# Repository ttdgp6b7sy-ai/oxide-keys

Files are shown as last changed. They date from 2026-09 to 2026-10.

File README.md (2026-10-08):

# Oxide Keys

A mini game console with 8 keys and a display, which has the ability to play very simple games to kill time and also a fun way to integrate Rust (the language I am learning).

The hardware is mainly composed of an 8-key mini game player with rotary encoder, LCD display that folds on a hinge, and RGB underglow on the Raspberry Pi Pico W, where I aim to include as much Rust as I can in this project.

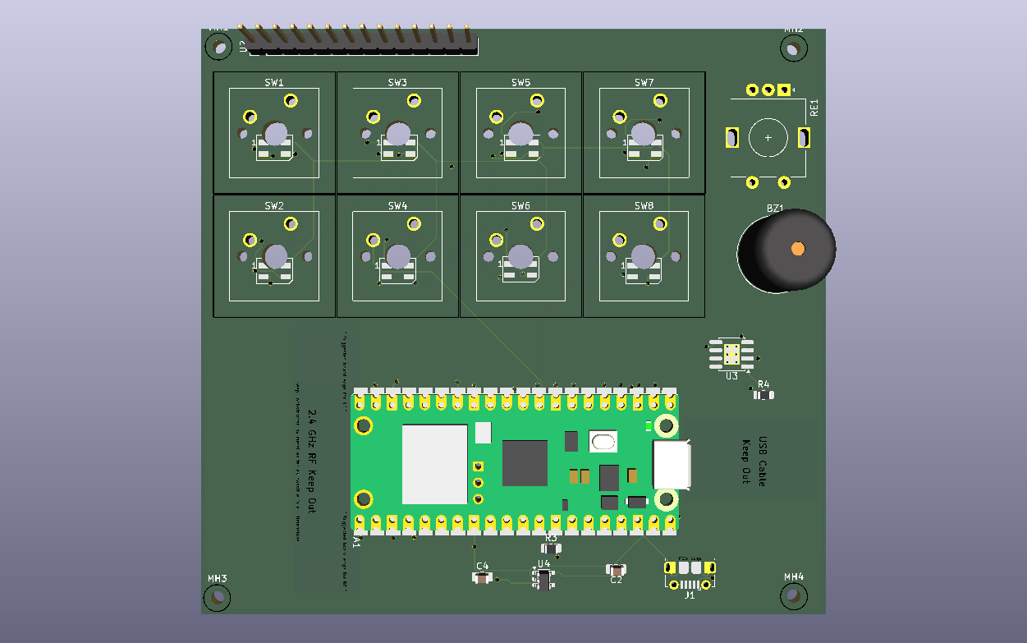
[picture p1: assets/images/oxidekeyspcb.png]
Oxide Keys Pcb Board





## CAD views
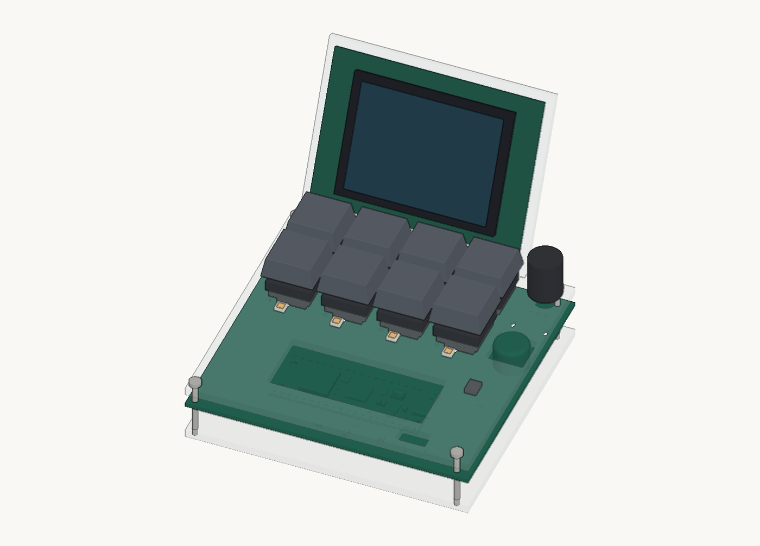
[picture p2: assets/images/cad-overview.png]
Oxide Keys with the parts in place

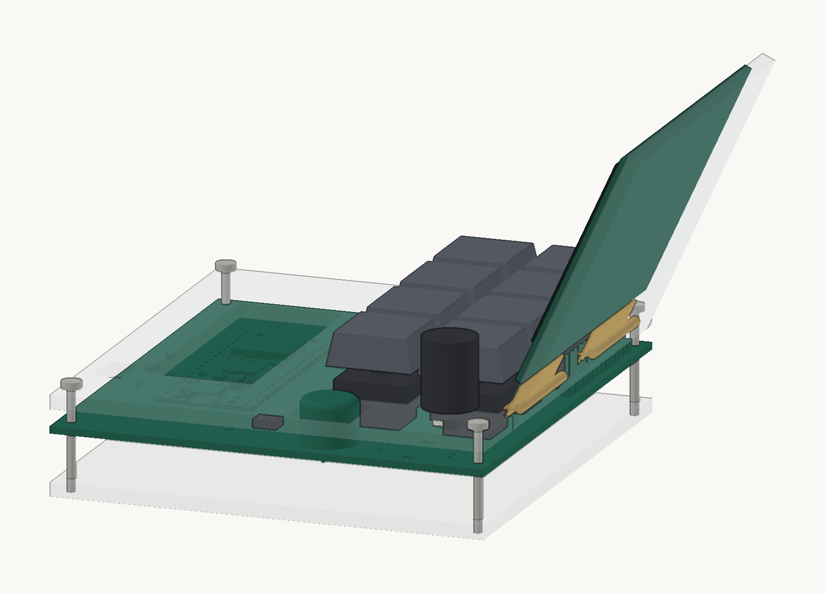
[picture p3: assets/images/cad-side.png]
Oxide Keys CAD from the side

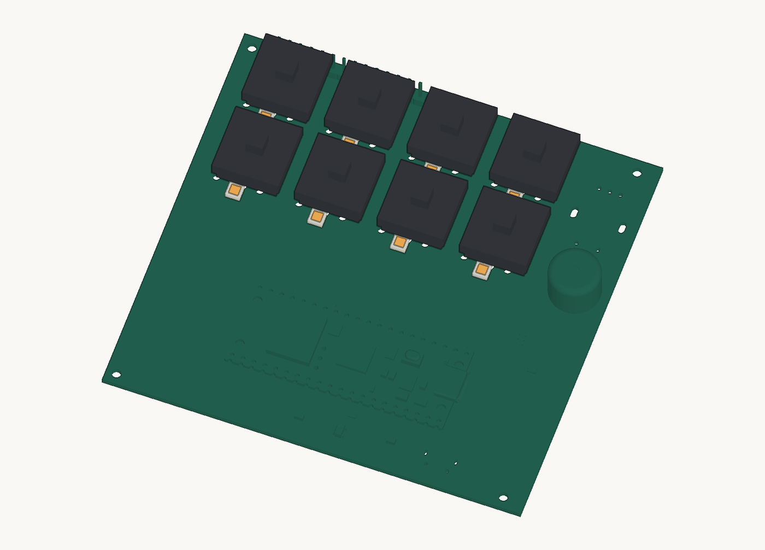
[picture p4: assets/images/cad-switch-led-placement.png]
Switches and LEDs on the PCB

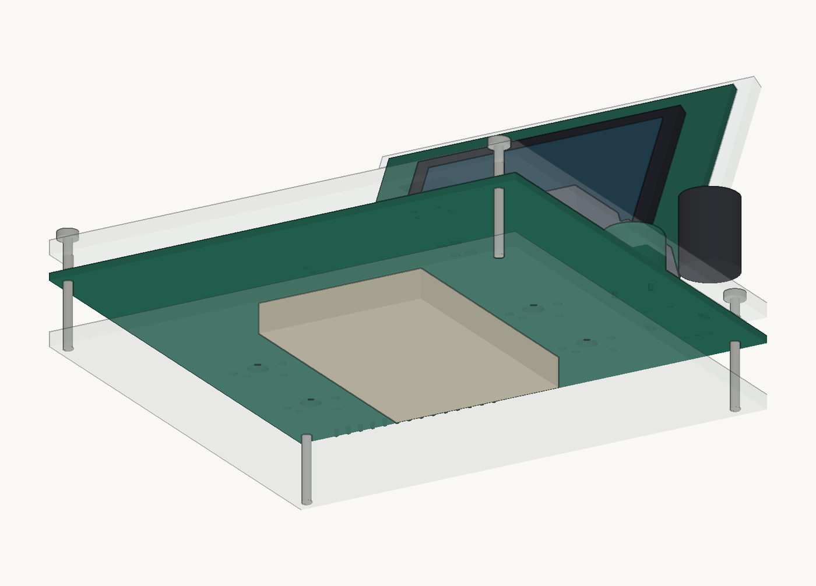
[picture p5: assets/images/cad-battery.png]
Battery below the PCB


[Assembly STEP](cad/OxideKeys-review-assembly-detailed.step) · [Enclosure SVG](cad/Oxidekeysenclosure.svg)

## Demo
No physical build yet but the image above shows the PCB board to be made.

## Location of stuff
- `firmware/` Rust code for the Pico W
- `pcb/` KiCad project and gerbers
- `cad/` 3D model and layout for enclosure
- `BOM.csv` parts list

## Quickstart

**Get the files**
Clone the repo or download extract zip from github repo.
`git clone https://github.com/ttdgp6b7sy-ai/oxide-keys.git`
`cd oxide-keys`

**Flash the firmware**
1. Hold the bootsel button on the pico W while plugging it into USB, it will appear as a drive.
2. Drag `firmware/oxide-keys.uf2` onto that drive and then it reboots on its own.

**Build the firmware yourself**
1. install rust from https://rustup.rs if you haven't already
2. `rustup target add thumbv6m-none-eabi`
3. `cargo install flip-link elf2uf2-rs --locked`
4. `cd firmware`, then `cargo build --release`
5.  convert to UF2: `elf2uf2-rs target/thumbv6m-none-eabi/release/oxide-keys oxide-keys.uf2`, then drag it onto the pico as above

**3d model**
The full assembly is `cad/OxideKeys-review-assembly-detailed.step`

## Features that I will implement
- The switches are designed so that each key is important in navigating the screen where I want to create a launcher which you can scroll through a section of simple games similar to pong and space invader that I create. These keys will be assigned certain roles in the future such as selecting, navigation (mimicking the hjkl keys etc), and the amount of keys allows a wide use-case in games that I will develop specifically for this device.
- The lights underneath the keys will be an amber glow until pressed in which they will react in a white colour once pressed.
- Want the encoder knob to be used to scroll on the idle screen/Launcher.

## Design
- Uses a pico W as the controller.
- firmware stack includes embedded hal, probers and rp2040 hal. It lives in firmware/ and builds with cargo build
- display sits on a hinge now
- fullparts list is in [BOM.csv](BOM.csv).
- the cad enclosure that I am incorporating uses a 2d laser cut acrylic with mounted standoffs in between. Meaning that I can still incorporate cool aesthetics with the layer being transparent on purpose.

## Todo
The potential of the encoder knob in some games is something I want to explore.

## Credits
credits to stardance for inspo + help.

## Bill of materials

The source BOM with supplier links is in [BOM.csv](BOM.csv).

| Part | Quantity | Price AUD | Supplier | Link |
| --- | ---: | ---: | --- | --- |
| Raspberry Pi Pico W | 1 | 9.90 | Core Electronics | [link](https://core-electronics.com.au/raspberry-pi-pico-w-wireless-wifi.html) |
| Piezo Buzzer | 1 | 0.34 | Core Electronics | [link](https://core-electronics.com.au/piezo-buzzer.html) |
| LiPo Battery 3.7V 1100mAh | 1 | 10.15 | Tempero Systems | [link](https://temperosystems.com.au/products/603450-lithium-ion-polymer-battery-lipo-3-7v-1100mah/) |
| Core Electronics Shipping | 1 | 7.00 | Core Electronics | [link](https://core-electronics.com.au/policies-faq) |
| Cherry MX2A Orange Switch pack (10x) | 1 | 6.50 | Mechstock | [link](https://www.mechstock.com.au/products/cherry-mx2a-orange) |
| Mechstock Shipping | 1 | 7.50 | Mechstock | [link](https://www.mechstock.com.au/pages/shipping-policy-2025) |
| Rotary Encoder Switch (SR1230) | 1 | 10.25 | Jaycar | [link](https://www.jaycar.com.au/rotary-encoder-switch-with-pushbutton/p/SR1230) |
| Silicone Wire 2m (28AWG Red + Black) | 1 | 4.95 | Amazon AU | [link](https://www.amazon.com.au/Ozchillon-28AWG-Flexible-Silicone-Black/dp/B0FTVY5H6M) |
| Pin Header Strip 40-way (M+F) | 1 | 2.95 | Jaycar | [link](https://www.jaycar.com.au/pcb-pins-and-headers/c/1HJ) |
| 1N4148 Diode Pack (5x) | 1 | 0.95 | Jaycar | [link](https://www.jaycar.com.au/1n4148-1n914-signal-diode-pack-of-5/p/ZR1100) |
| 2.4" TFT LCD Touch Display (ILI9341) | 1 | 10.00 | Createunsw | [link](https://store.createunsw.com.au/2-4-arduino-touchscreen-module) |
| M2 Nylon Standoff Kit (180pc) | 1 | 15.00 | Amazon AU | [link](https://www.amazon.com.au/Aolidsive-Standoff-Assortment-Motherboard-Projects/dp/B0GYBV21GF) |
| Clear Acrylic Sheet A5 3mm | 2 | 8.96 | Amazon AU | [link](https://www.amazon.com.au/Clear-Acrylic-Sheet-3mm-Thickness/dp/B0F4PN42ZM) |
| Knurled Encoder Knob (2pc) | 1 | 7.34 | Core-electronics | [link](https://core-electronics.com.au/slim-rubber-rotary-encoder-knob-11-5mm-x-14-5mm-d-shaft.html) |
| N3UD PBT Blank Keycaps 1U XDA Profile (20pc) | 1 | 7.00 | AliExpress | [link](https://www.aliexpress.com/w/wholesale-n3ud-20pcs-pbt-blank-keycap-xda.html) |
| Amazon AU Shipping (order remaining Amazon items together) | 1 | 0.00 | Amazon AU | [link](https://www.amazon.com.au/) |
| SK6812MINI RGB LED pack (x20) | 2 | 3.00 | KEEBD | [link](https://keebd.com/products/sk6812mini-rgb-led) |
| KEEBD Shipping | 1 | 9.59 | KEEBD | [link](https://keebd.com/) |
| TP4056 Li-ion Charger IC (harvest from domestic TP4056 module) | 1 | 3.99 | Tempero Systems | [link](https://temperosystems.com.au/products/tp4056-mini-usb-1a-5v-lithium-battery-charger-copy/) |
| AP2112K-3.3 LDO Regulator | 1 | 5.23 | Amazon AU | [link](https://www.amazon.com.au/) |
| 330 Ohm 0805 Resistor pack (10x) | 1 | 1.40 | Altronics | [link](https://www.altronics.com.au/electronic-components/carbon-film-resistors/?prdv=330R) |
| 1uF 0805 Capacitor pack (50x) | 1 | 13.95 | Phipps Electronics | [link](https://www.phippselectronics.com/product/16v-1uf-0805-ceramic-smd-capacitor-pack-of-50/) |
| Brass Hinges (2-pack) | 1 | 7.94 | Bunnings | [link](https://www.bunnings.com.au/prestige-15-x-25-x-0-5mm-decorative-brass-hinges_p3968293) |
| Bunnings Shipping | 1 | 0.00 | Bunnings | [link](https://www.bunnings.com.au/) |
| TOTAL (including PCB fabrication) |  | 161.79 |  |  |
| JLCPCB 4-Layer PCB Fab | 1 | 13.00 | JLCPCB | [link](https://jlcpcb.com/) |
| --- Optional, not counted above --- |  |  |  |  |
| Desertcart M2 Mounting Screw Kit (60pc) | 1 | 10.00 | Desertcart Australia | [link](https://www.desertcart.com.au/products/600128736-m2-ssd-screws-kit-pcie-nvme-m-2-ssd-mounting) |
| Soldering Iron Kit (optional) | 1 | 25.00 | Amazon AU | [link](https://www.amazon.com.au/Soldering-Iron-Kit-Rechargeable-Temperature/dp/B0DYH7QMYK) |

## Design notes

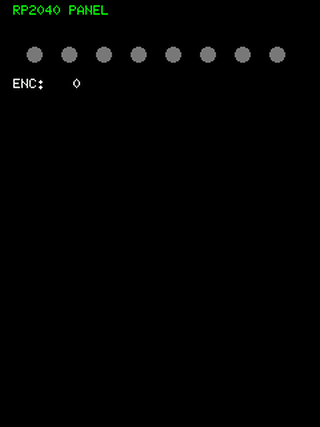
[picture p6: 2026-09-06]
firmware/wokwi-demo.gif

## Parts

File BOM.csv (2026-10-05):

Part | Quantity | Price_AUD | Price_USD | Supplier | Link | Group | Shipping
Raspberry Pi Pico W | 1 | 9.90 | 7.11 | Core Electronics | https://core-electronics.com.au/raspberry-pi-pico-w-wireless-wifi.html | Core Electronics
Piezo Buzzer | 1 | 0.34 | 0.24 | Core Electronics | https://core-electronics.com.au/piezo-buzzer.html | Core Electronics
LiPo Battery 3.7V 1100mAh | 1 | 10.15 | 7.29 | Tempero Systems | https://temperosystems.com.au/products/603450-lithium-ion-polymer-battery-lipo-3-7v-1100mah/ | Tempero Systems
Core Electronics Shipping | 1 | 7.00 | 5.03 | Core Electronics | https://core-electronics.com.au/policies-faq | Core Electronics | Standard Post
Cherry MX2A Orange Switch pack (10x) | 1 | 6.50 | 4.69 | Mechstock | https://www.mechstock.com.au/products/cherry-mx2a-orange | Mechstock
Mechstock Shipping | 1 | 7.50 | 5.39 | Mechstock | https://www.mechstock.com.au/pages/shipping-policy-2025 | Mechstock | Standard Post (est.)
Rotary Encoder Switch (SR1230) | 1 | 10.25 | 7.36 | Jaycar | https://www.jaycar.com.au/rotary-encoder-switch-with-pushbutton/p/SR1230 | Jaycar
Silicone Wire 2m (28AWG Red + Black) | 1 | 4.95 | 3.57 | Amazon AU | https://www.amazon.com.au/Ozchillon-28AWG-Flexible-Silicone-Black/dp/B0FTVY5H6M | Amazon AU
Pin Header Strip 40-way (M+F) | 1 | 2.95 | 2.12 | Jaycar | https://www.jaycar.com.au/pcb-pins-and-headers/c/1HJ | Jaycar
1N4148 Diode Pack (5x) | 1 | 0.95 | 0.68 | Jaycar | https://www.jaycar.com.au/1n4148-1n914-signal-diode-pack-of-5/p/ZR1100 | Jaycar
2.4" TFT LCD Touch Display (ILI9341) | 1 | 10.00 | 7.22 | Createunsw | https://store.createunsw.com.au/2-4-arduino-touchscreen-module | createunsw
M2 Nylon Standoff Kit (180pc) | 1 | 15.00 | 10.77 | Amazon AU | https://www.amazon.com.au/Aolidsive-Standoff-Assortment-Motherboard-Projects/dp/B0GYBV21GF | Amazon AU
Clear Acrylic Sheet A5 3mm | 2 | 8.96 | 6.43 | Amazon AU | https://www.amazon.com.au/Clear-Acrylic-Sheet-3mm-Thickness/dp/B0F4PN42ZM | Amazon AU
Knurled Encoder Knob (2pc) | 1 | 7.34 | 5.27 | Core-electronics | https://core-electronics.com.au/slim-rubber-rotary-encoder-knob-11-5mm-x-14-5mm-d-shaft.html | Core Electronics
N3UD PBT Blank Keycaps 1U XDA Profile (20pc) | 1 | 7.00 | 5.03 | AliExpress | https://www.aliexpress.com/w/wholesale-n3ud-20pcs-pbt-blank-keycap-xda.html | AliExpress
Amazon AU Shipping (order remaining Amazon items together) | 1 | 0.00 | 0.00 | Amazon AU | https://www.amazon.com.au/ | Amazon AU | Free (combined order over threshold)
SK6812MINI RGB LED pack (x20) | 2 | 3.00 | 2.15 | KEEBD | https://keebd.com/products/sk6812mini-rgb-led | KEEBD
KEEBD Shipping | 1 | 9.59 | 6.88 | KEEBD | https://keebd.com/ | KEEBD | Standard Post
TP4056 Li-ion Charger IC (harvest from domestic TP4056 module) | 1 | 3.99 | 2.87 | Tempero Systems | https://temperosystems.com.au/products/tp4056-mini-usb-1a-5v-lithium-battery-charger-copy/ | Tempero Systems
AP2112K-3.3 LDO Regulator | 1 | 5.23 | 3.76 | Amazon AU | https://www.amazon.com.au/ | Amazon AU | Included in combined Amazon AU shipping
330 Ohm 0805 Resistor pack (10x) | 1 | 1.40 | 1.01 | Altronics | https://www.altronics.com.au/electronic-components/carbon-film-resistors/?prdv=330R | Altronics
1uF 0805 Capacitor pack (50x) | 1 | 13.95 | 10.01 | Phipps Electronics | https://www.phippselectronics.com/product/16v-1uf-0805-ceramic-smd-capacitor-pack-of-50/ | Phipps Electronics
Brass Hinges (2-pack) | 1 | 7.94 | 5.70 | Bunnings | https://www.bunnings.com.au/prestige-15-x-25-x-0-5mm-decorative-brass-hinges_p3968293 | Bunnings | In-store / Click & Collect
Bunnings Shipping | 1 | 0.00 | 0.00 | Bunnings | https://www.bunnings.com.au/ | Bunnings | In-store / Click & Collect
TOTAL (including PCB fabrication) |  | 161.79 | 116.32
JLCPCB 4-Layer PCB Fab | 1 | 13.00 | 9.34 | JLCPCB | https://jlcpcb.com/ | JLCPCB | Counted toward US$120 limit
--- Optional, not counted above ---
Desertcart M2 Mounting Screw Kit (60pc) | 1 | 10.00 | 7.20 | Desertcart Australia | https://www.desertcart.com.au/products/600128736-m2-ssd-screws-kit-pcie-nvme-m-2-ssd-mounting | Optional | Approx. A$10 duties & taxes included
Soldering Iron Kit (optional) | 1 | 25.00 | 17.95 | Amazon AU | https://www.amazon.com.au/Soldering-Iron-Kit-Rechargeable-Temperature/dp/B0DYH7QMYK | Optional

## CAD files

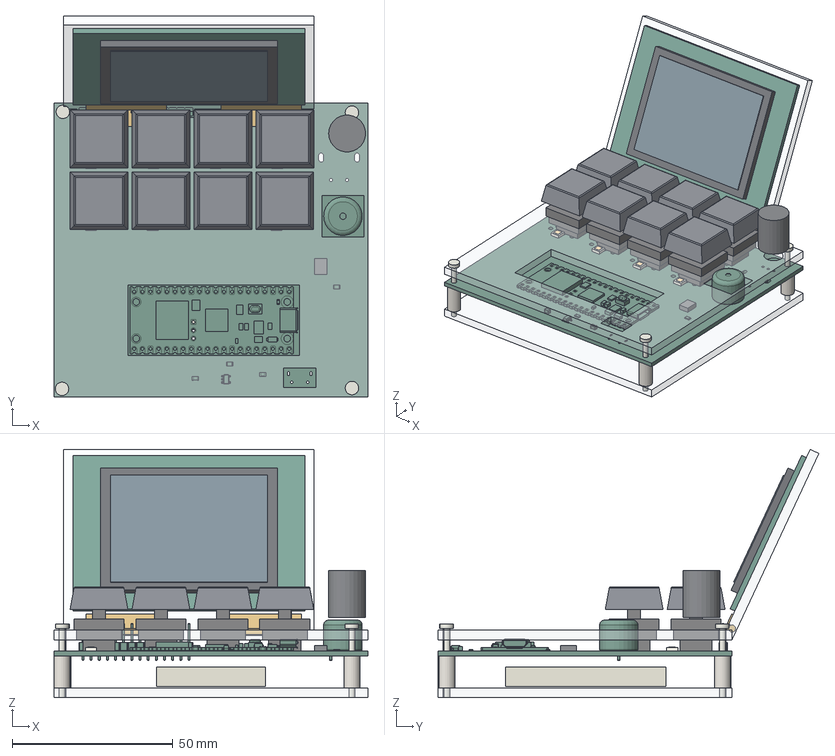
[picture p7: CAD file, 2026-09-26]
cad/OxideKeys-review-assembly-detailed.step
97.8 x 118.5 x 77.3 mm
KiCad PCB export
SW1 Cherry MX2A Orange - review geometry
SW2 Cherry MX2A Orange - review geometry
SW3 Cherry MX2A Orange - review geometry
SW4 Cherry MX2A Orange - review geometry
SW5 Cherry MX2A Orange - review geometry
SW6 Cherry MX2A Orange - review geometry
SW7 Cherry MX2A Orange - review geometry
SW8 Cherry MX2A Orange - review geometry
D1 SK6812MINI housing - review geometry
D2 SK6812MINI housing - review geometry
D3 SK6812MINI housing - review geometry
D4 SK6812MINI housing - review geometry
D5 SK6812MINI housing - review geometry
D6 SK6812MINI housing - review geometry
D7 SK6812MINI housing - review geometry
D8 SK6812MINI housing - review geometry
K1 PBT blank keycap - nominal
K2 PBT blank keycap - nominal
K3 PBT blank keycap - nominal
K4 PBT blank keycap - nominal
K5 PBT blank keycap - nominal
K6 PBT blank keycap - nominal
K7 PBT blank keycap - nominal
K8 PBT blank keycap - nominal
MAR2406 8-bit display PCB - 72.2 x 52.7 mm
MAR2406 display bezel - approximate
MAR2406 display active area - 48.96 x 36.72 mm
11.5 x 14.5 mm encoder knob
603450 LiPo 6 x 34 x 50 mm - provisional under-board placement
U3 TP4056 charger IC - nominal SOIC-8
H1 25 x 15 mm brass hinge - illustrative
H2 25 x 15 mm brass hinge - illustrative
M2 nylon screw 1 - nominal
M2 nylon screw 2 - nominal
M2 nylon screw 3 - nominal
M2 nylon screw 4 - nominal
D1 LED lens
D2 LED lens
D3 LED lens
D4 LED lens
D5 LED lens
D6 LED lens
D7 LED lens
D8 LED lens
3mm base plate
3mm switch deck
3mm display flap - open position
illustrative spacer 1
illustrative spacer 2
illustrative spacer 3
illustrative spacer 4

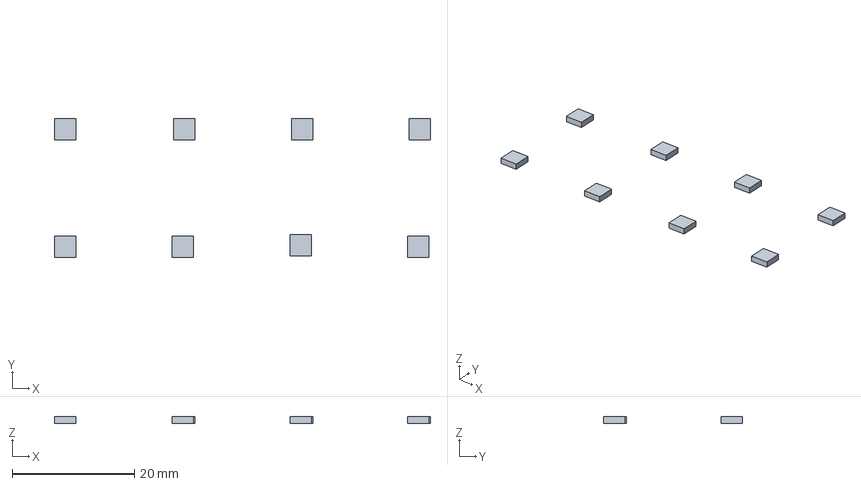
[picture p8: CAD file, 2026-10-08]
cad/leds.step
61.5 x 22.8 x 1.10 mm

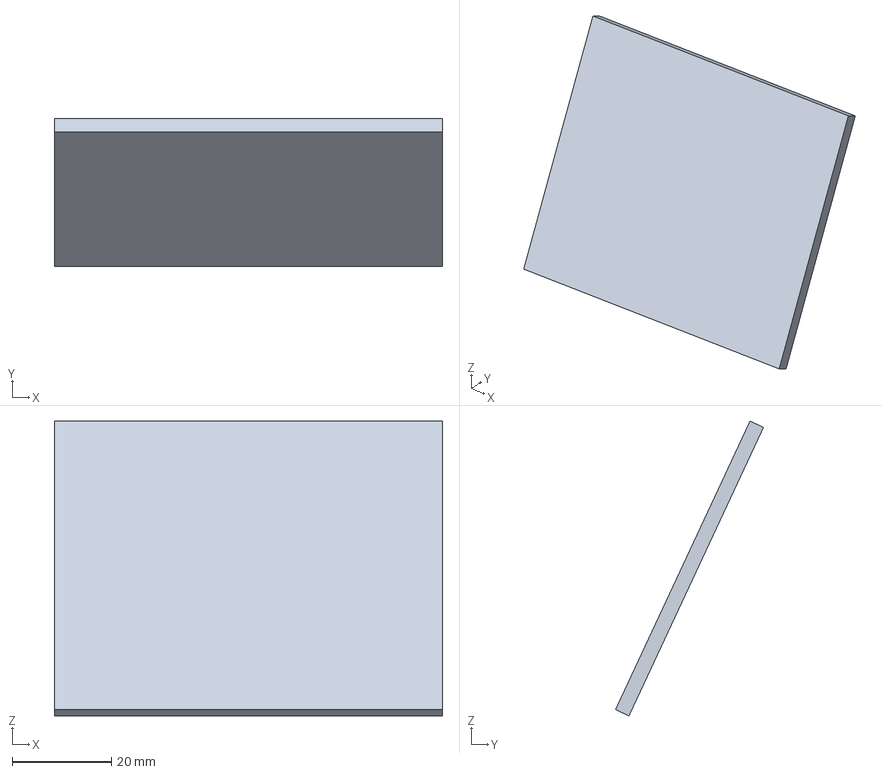
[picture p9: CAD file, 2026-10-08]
cad/display-flap-open.step
78.0 x 29.8 x 59.3 mm

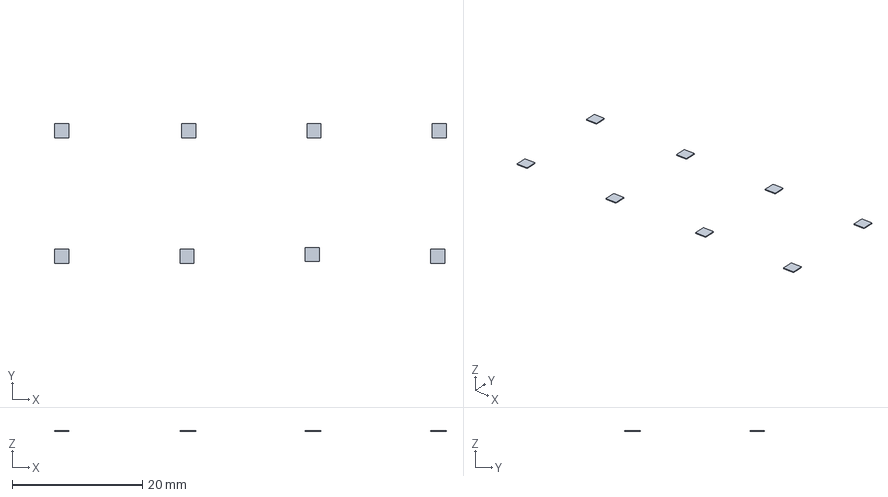
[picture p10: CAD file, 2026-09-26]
cad/led-lenses.step
60.2 x 21.4 x 0.15 mm

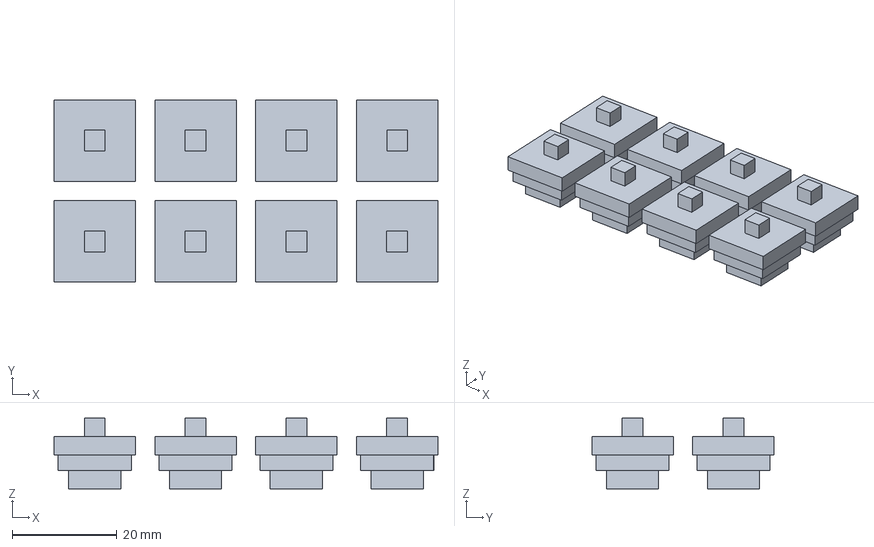
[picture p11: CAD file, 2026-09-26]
cad/switches.step
73.5 x 34.9 x 13.5 mm

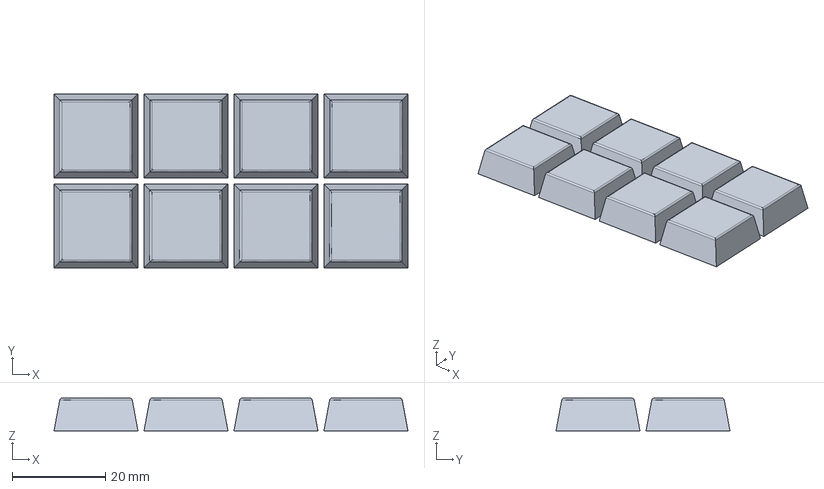
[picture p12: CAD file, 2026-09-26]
cad/keycaps.step
75.9 x 37.3 x 7.00 mm

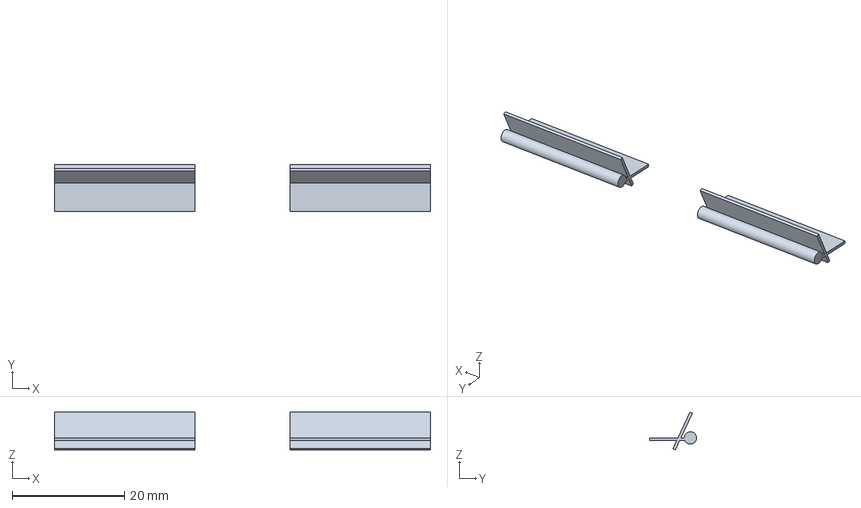
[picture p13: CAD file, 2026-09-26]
cad/hinges.step
67.0 x 8.40 x 6.74 mm

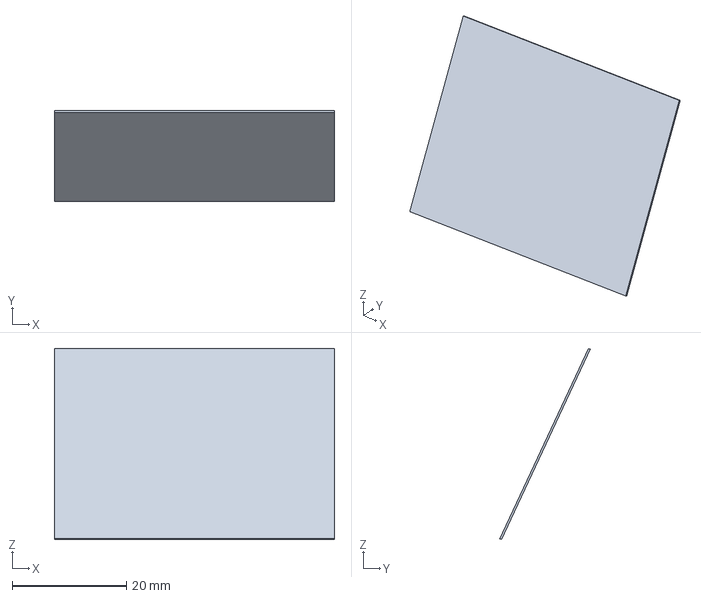
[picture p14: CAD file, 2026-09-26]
cad/display-glass.step
49.0 x 15.8 x 33.4 mm

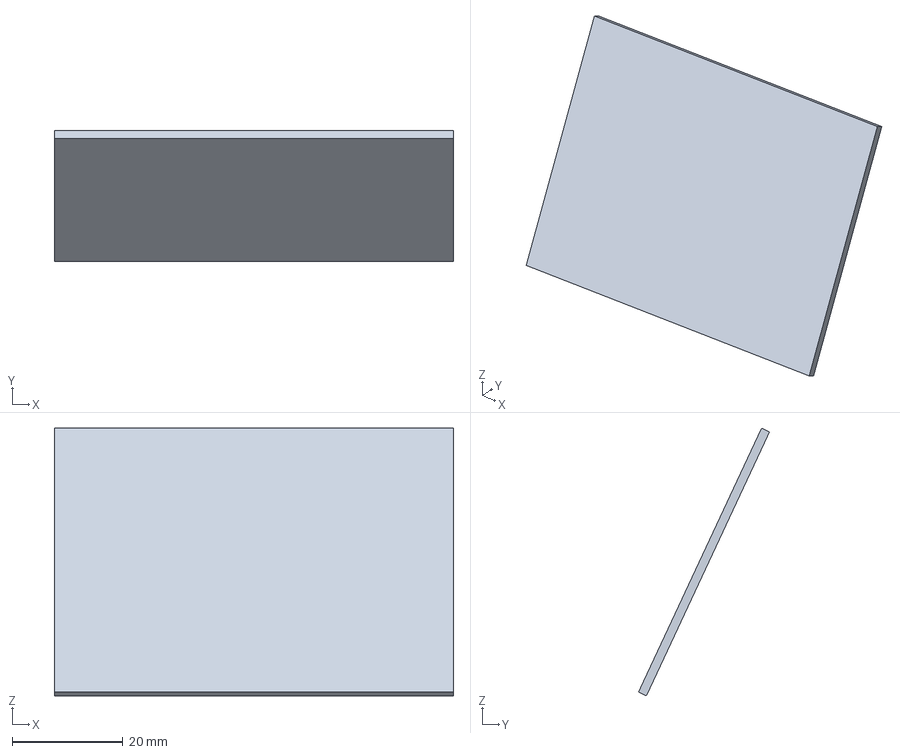
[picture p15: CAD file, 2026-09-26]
cad/display-board.step
72.2 x 23.7 x 48.4 mm

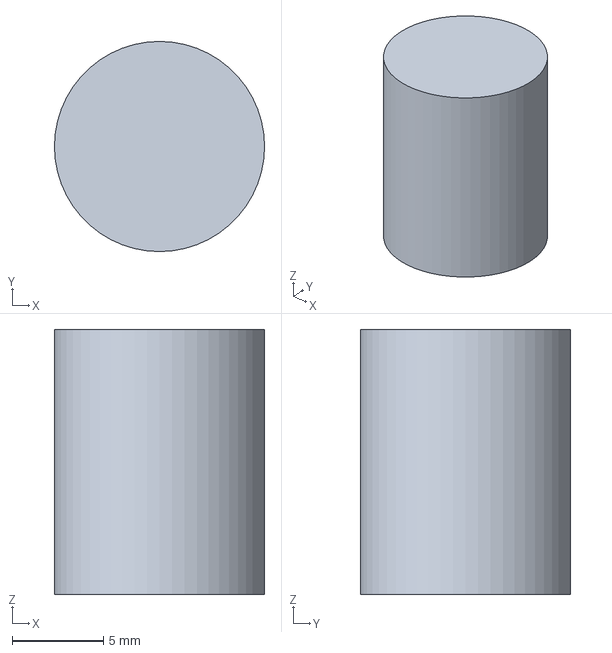
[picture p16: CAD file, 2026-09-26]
cad/knob.step
11.5 x 11.5 x 14.5 mm

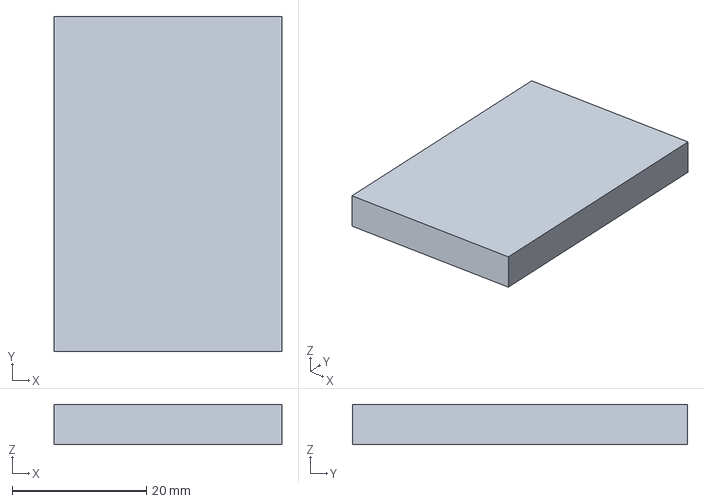
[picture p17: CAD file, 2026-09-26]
cad/battery.step
34.0 x 50.0 x 6.00 mm

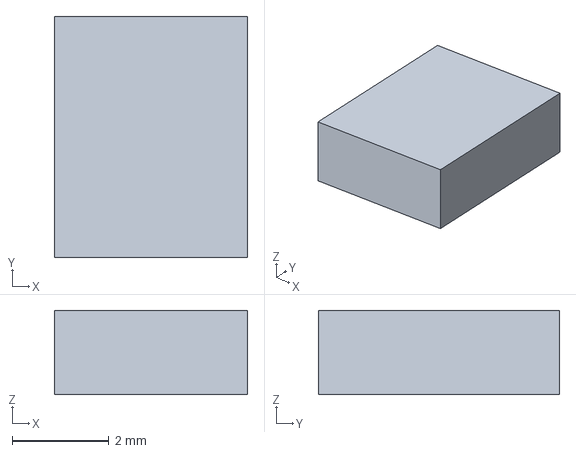
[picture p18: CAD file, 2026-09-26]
cad/charger.step
4.00 x 5.00 x 1.75 mm

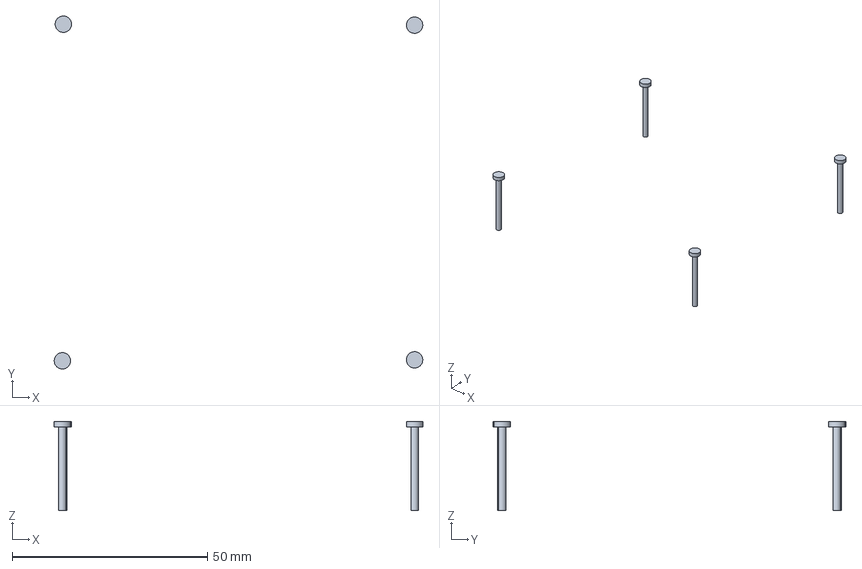
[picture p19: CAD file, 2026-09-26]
cad/fasteners.step
94.4 x 90.4 x 22.9 mm

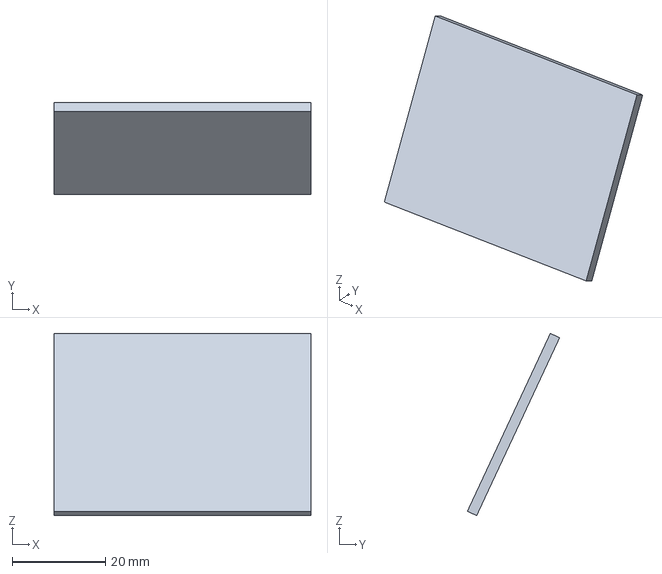
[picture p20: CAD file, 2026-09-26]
cad/display-bezel.step
55.0 x 19.7 x 39.0 mm

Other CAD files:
cad/base-plate.step
cad/switch-deck.step
cad/pcbfirstdesign.step

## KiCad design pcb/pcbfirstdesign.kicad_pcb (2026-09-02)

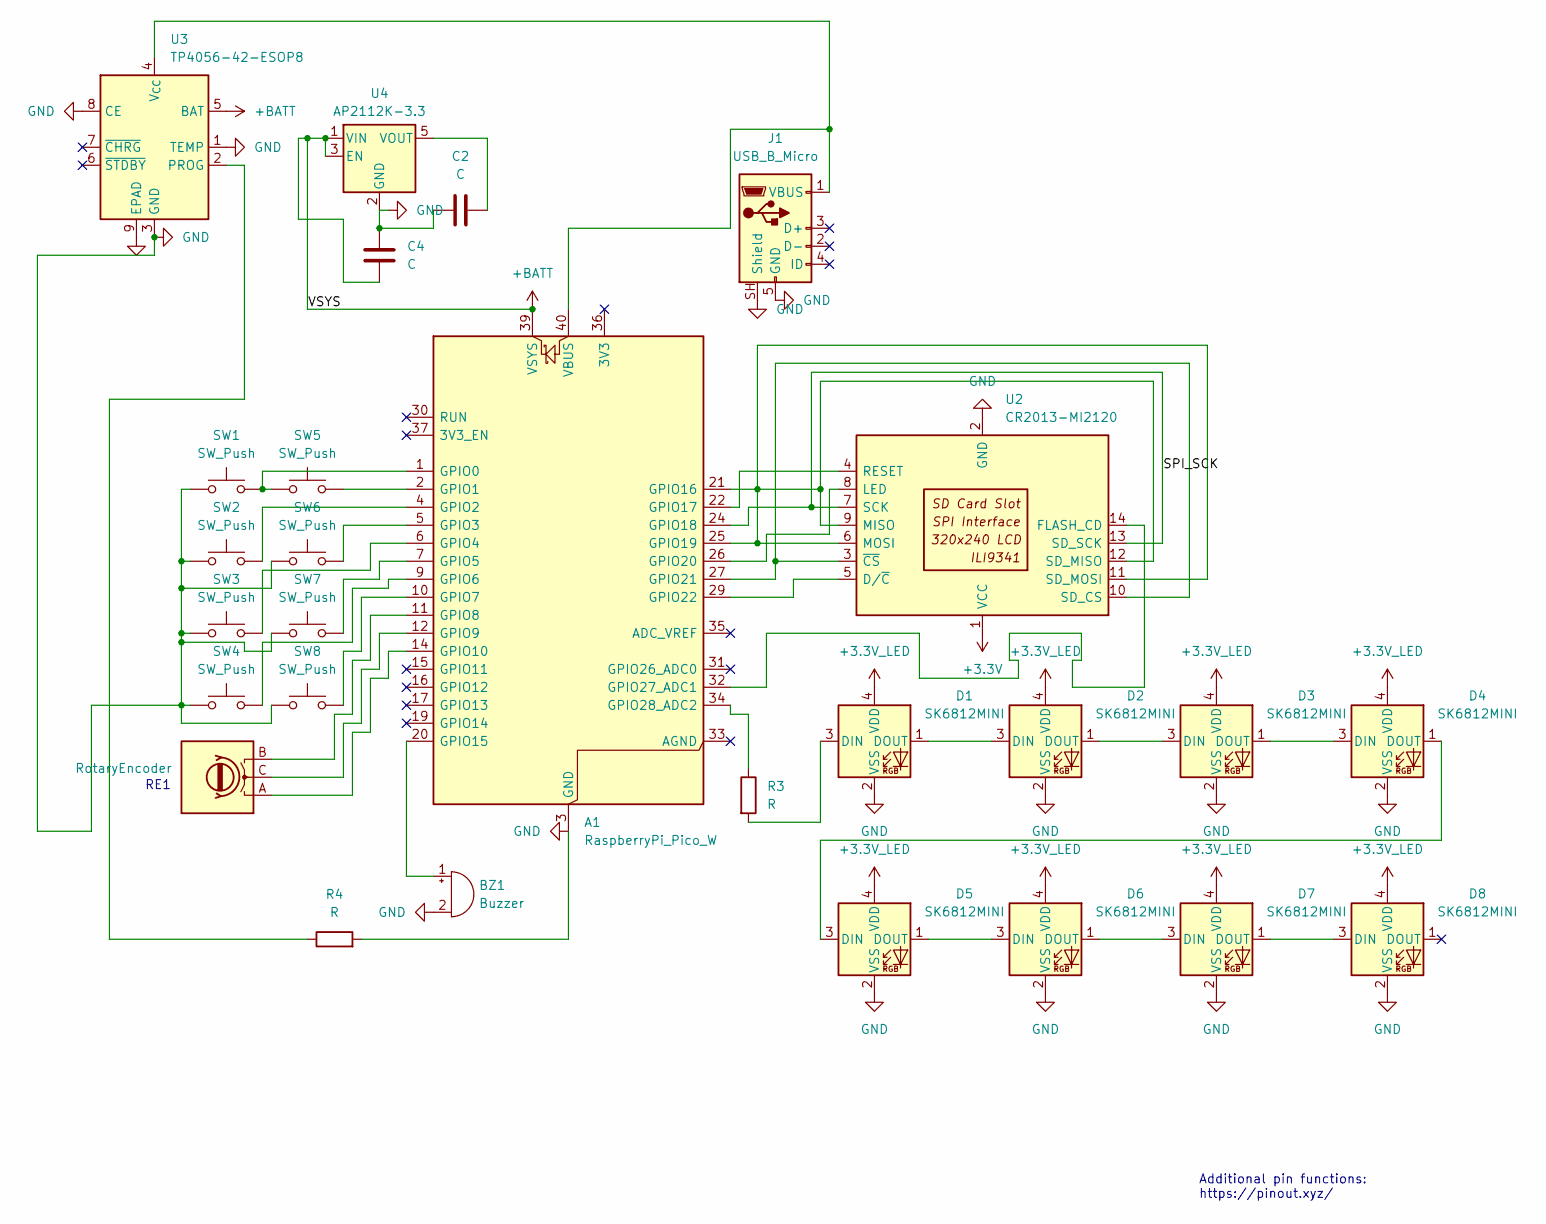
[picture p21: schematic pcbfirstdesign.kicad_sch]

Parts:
A1: RaspberryPi_Pico_W; RaspberryPi_Pico_W_SMD_HandSolder
BZ1: Buzzer; Buzzer_12x9.5RM7.6
C2, C4: C; C_0805_2012Metric_Pad1.18x1.45mm_HandSolder
D1, D2, D3, D4, D5, D6, D7, D8: SK6812MINI; LED_SK6812MINI_PLCC4_3.5x3.5mm_P1.75mm
J1: USB_B_Micro; USB_Micro-B_Molex-105017-0001
R3, R4: R; R_0805_2012Metric_Pad1.20x1.40mm_HandSolder
RE1: RotaryEncoder; RotaryEncoder_Alps_EC11E-Switch_Vertical_H20mm
SW1, SW2, SW3, SW4, SW5, SW6, SW7, SW8: SW_Push; SW_Cherry_MX_1.00u_PCB
U2: CR2013-MI2120; PinHeader_1x14_P2.54mm_Vertical
U3: TP4056-42-ESOP8; SOIC-8-1EP_3.9x4.9mm_P1.27mm_EP2.41x3.3mm_ThermalVias
U4: AP2112K-3.3; SOT-23-5

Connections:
+3.3V: U2.1 (VCC)
+3.3V_LED: D1.4 (VDD), D2.4 (VDD), D3.4 (VDD), D4.4 (VDD), D5.4 (VDD), D6.4 (VDD), D7.4 (VDD), D8.4 (VDD)
+BATT: A1.39 (VSYS), C4.2, U3.5 (BAT), U4.1 (VIN), U4.3 (EN)
/SPI_SCK: A1.24 (GPIO18), U2.7 (SCK), U2.13 (SD_SCK)
GND: A1.3 (GND), A1.8 (GND), A1.13 (GND), A1.18 (GND), A1.23 (GND), A1.28 (GND), A1.38 (GND), BZ1.2 (-), C2.2, C4.1, D1.2 (VSS), D2.2 (VSS), D3.2 (VSS), D4.2 (VSS), D5.2 (VSS), D6.2 (VSS), D7.2 (VSS), D8.2 (VSS), J1.5 (GND), J1.SH (Shield), R4.2, SW1.1, SW2.1, SW3.1, SW4.1, SW6.1, SW7.1, SW8.1, U2.2 (GND), U3.1 (TEMP), U3.3 (GND), U3.8 (CE), U3.9 (EPAD), U4.2 (GND)
unnamed: A1.1 (GPIO0), SW1.2, SW5.1
unnamed: A1.2 (GPIO1), SW5.2
unnamed: A1.4 (GPIO2), SW2.2
unnamed: A1.5 (GPIO3), SW6.2
unnamed: A1.6 (GPIO4), SW3.2
unnamed: A1.7 (GPIO5), SW7.2
unnamed: A1.9 (GPIO6), SW4.2
unnamed: A1.10 (GPIO7), SW8.2
unnamed: A1.11 (GPIO8), RE1.B
unnamed: A1.12 (GPIO9), RE1.C
unnamed: A1.14 (GPIO10), RE1.A
unnamed: A1.20 (GPIO15), BZ1.1 (+)
unnamed: A1.21 (GPIO16), A1.25 (GPIO19), U2.6 (MOSI), U2.9 (MISO), U2.11 (SD_MOSI), U2.12 (SD_MISO)
unnamed: A1.22 (GPIO17), U2.4 (RESET)
unnamed: A1.26 (GPIO20), U2.8 (LED)
unnamed: A1.27 (GPIO21), U2.3 (~CS), U2.10 (SD_CS)
unnamed: A1.29 (GPIO22), U2.5 (D/~C)
unnamed: A1.32 (GPIO27_ADC1), U2.14 (FLASH_CD)
unnamed: A1.34 (GPIO28_ADC2), R3.1
unnamed: A1.40 (VBUS), J1.1 (VBUS), U3.4 (V_{CC})
unnamed: D1.3 (DIN), R3.2
unnamed: D1.1 (DOUT), D2.3 (DIN)
unnamed: D2.1 (DOUT), D3.3 (DIN)
unnamed: D3.1 (DOUT), D4.3 (DIN)
unnamed: D4.1 (DOUT), D5.3 (DIN)
unnamed: D5.1 (DOUT), D6.3 (DIN)
unnamed: D6.1 (DOUT), D7.3 (DIN)
unnamed: D7.1 (DOUT), D8.3 (DIN)
unnamed: R4.1, U3.2 (PROG)
unnamed: C2.1, U4.5 (VOUT)

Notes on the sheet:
Additional pin functions: https://pinout.xyz/
RE1

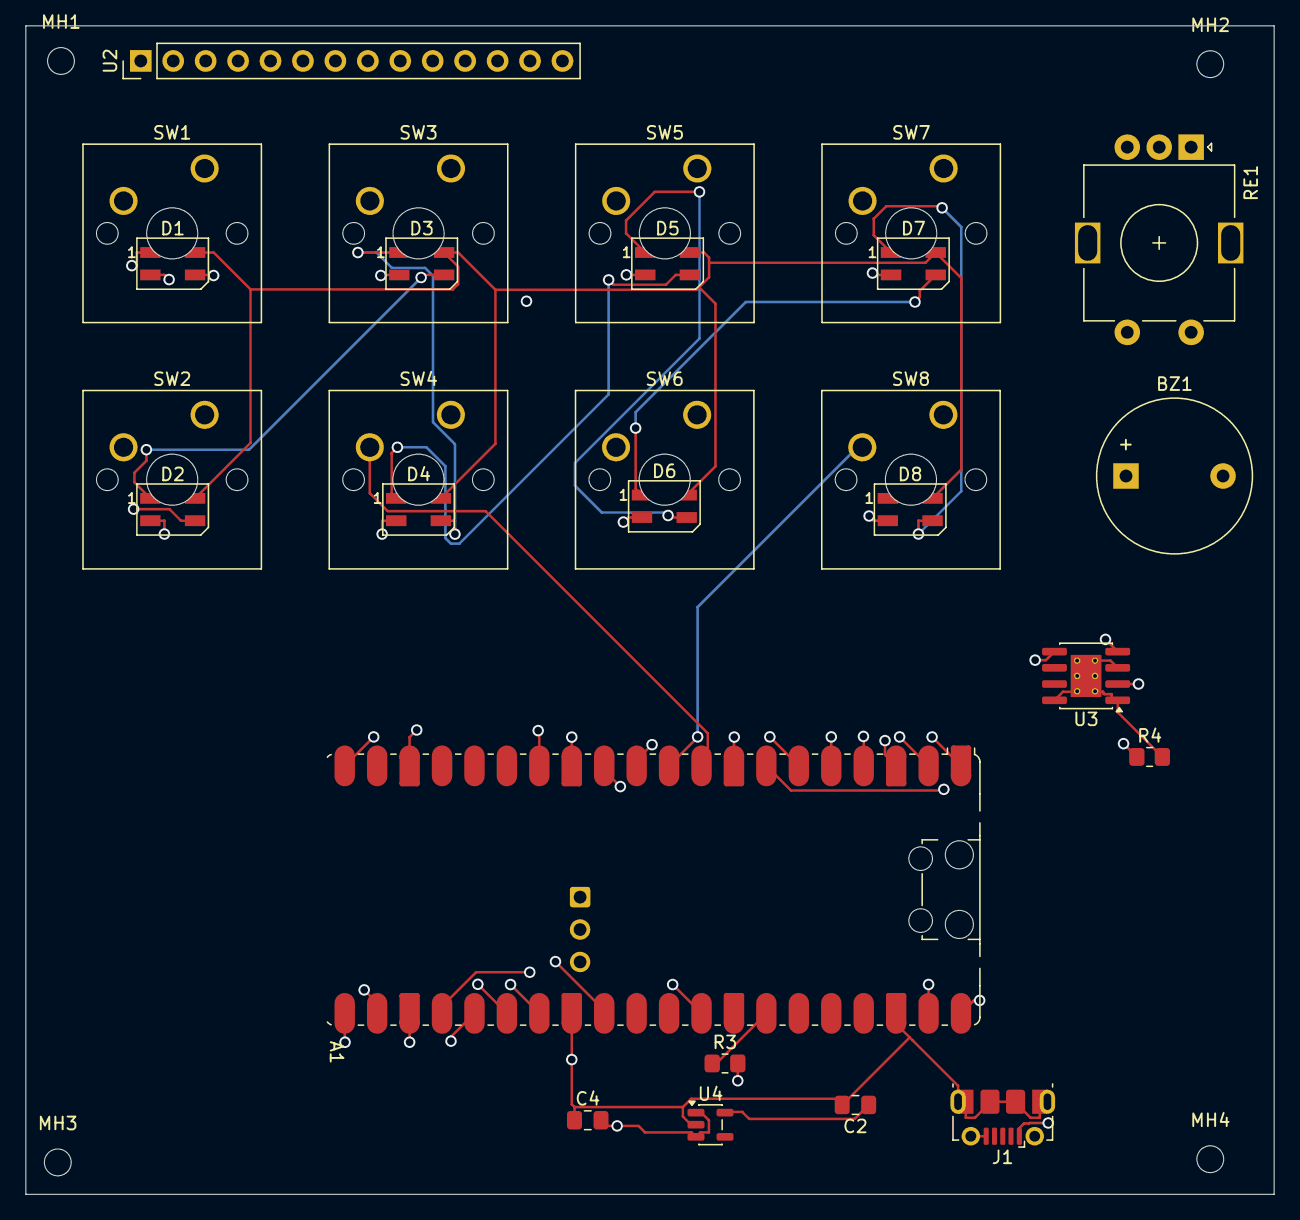
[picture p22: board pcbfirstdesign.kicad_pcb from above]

Board: 4 copper layers, 97.8 x 91.5 mm, 31 parts (0 on the bottom side), 34 nets.

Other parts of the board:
MH1, MH2, MH3, MH4: MountingHole_2.1mm

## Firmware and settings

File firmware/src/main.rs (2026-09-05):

#![no_std]
#![no_main]

use embedded_graphics::pixelcolor::Rgb565;
use embedded_graphics::prelude::RgbColor;
use embedded_hal::delay::DelayNs;
use embedded_hal::digital::OutputPin;
use panic_halt as _;
use rp2040_hal as hal;
use hal::clocks::Clock;
use hal::pac;

mod buzzer;
mod display;
mod encoder;
mod leds;
mod switches;

use switches::SwitchId;

#[link_section = ".boot2"]
#[used]
pub static BOOT2: [u8; 256] = rp2040_boot2::BOOT_LOADER_GENERIC_03H;

const XTAL_FREQ_HZ: u32 = 12_000_000;

#[rp2040_hal::entry]
fn main() -> ! {
    let mut peripherals = pac::Peripherals::take().unwrap();

    let mut watchdog = hal::Watchdog::new(peripherals.WATCHDOG);

    // set up the clocks, this depends on the crystal on the board
    let clocks = hal::clocks::init_clocks_and_plls(
        XTAL_FREQ_HZ,
        peripherals.XOSC,
        peripherals.CLOCKS,
        peripherals.PLL_SYS,
        peripherals.PLL_USB,
        &mut peripherals.RESETS,
        &mut watchdog,
    )
    .expect("clock init failed");

    let mut timer = rp2040_hal::Timer::new(peripherals.TIMER, &mut peripherals.RESETS, &clocks);

    let sio = hal::Sio::new(peripherals.SIO);
    let pins = hal::gpio::Pins::new(
        peripherals.IO_BANK0,
        peripherals.PADS_BANK0,
        sio.gpio_bank0,
        &mut peripherals.RESETS,
    );

    let mut led = pins.gpio25.into_push_pull_output();

    // the 8 switches on the panel, see switches.rs for which pin is which
    let mut switches = switches::Switches::new(
        pins.gpio0.into_pull_up_input(),
        pins.gpio1.into_pull_up_input(),
        pins.gpio2.into_pull_up_input(),
        pins.gpio4.into_pull_up_input(),
        pins.gpio6.into_pull_up_input(),
        pins.gpio3.into_pull_up_input(),
        pins.gpio5.into_pull_up_input(),
        pins.gpio7.into_pull_up_input(),
    );

    let mut encoder = encoder::Encoder::new(
        pins.gpio10.into_pull_up_input(),
        pins.gpio8.into_pull_up_input(),
        pins.gpio9.into_push_pull_output(),
    );

    let mut buzzer = buzzer::Buzzer::new(peripherals.PWM, &mut peripherals.RESETS, pins.gpio15);
    buzzer.stop(); // don't want it making noise on startup

    // 2.4" ili9341 screen on spi0, miso is wired up but don't use it
    let mut display = display::build(
        peripherals.SPI0,
        &mut peripherals.RESETS,
        clocks.peripheral_clock.freq(),
        pins.gpio18, // sck
        pins.gpio19, // mosi
        pins.gpio16, // miso
        pins.gpio17, // cs
        pins.gpio20, // dc
        pins.gpio21, // reset
        pins.gpio22, // backlight
        &mut timer,
    );

    let mut encoder_count = 0;
    let mut displayed_count = i32::MIN;
    let mut displayed_any_pressed = false;
    let mut number_buffer = [0u8; 8];

    loop {
        let now_ms = timer.get_counter().ticks() / 1000;
        switches.upd(now_ms);

        match encoder.upd() {
            encoder::Rot::Cw => encoder_count += 1,
            encoder::Rot::Ccw => encoder_count -= 1,
            encoder::Rot::None => {}
        }

        let mut any_pressed = false;
        for switch_id in SwitchId::ALL {
            if switches.pressed(switch_id) {
                any_pressed = true;
            }
        }

        // turn the status led on while any switch is held down
        if any_pressed {
            led.set_high().unwrap();
        } else {
            led.set_low().unwrap();
        }

        let display_changed =
            encoder_count != displayed_count || any_pressed != displayed_any_pressed;

        // only redraw about 5 times a second, and only if something changed
        if display_changed && now_ms % 200 < 20 {
            displayed_count = encoder_count;
            displayed_any_pressed = any_pressed;

            display.clear(Rgb565::BLACK);
            display.text("RP2040 PANEL", 10, 10, Rgb565::GREEN);

            let mut dot_x: i32 = 20;
            for switch_id in SwitchId::ALL {
                let color = if switches.pressed(switch_id) {
                    Rgb565::GREEN
                } else {
                    Rgb565::new(15, 30, 15) // dim gray, there's no gray constant
                };

                display.dot(dot_x, 35, color);
                dot_x += 26;
            }

            display.text("ENC:", 10, 65, Rgb565::WHITE);
            display.text(
                format_number(encoder_count, &mut number_buffer),
                55,
                65,
                Rgb565::WHITE,
            );
        }

        timer.delay_ms(10);
    }
}

// turns a number into text by hand since no_std and have no heap
fn format_number(number: i32, buffer: &mut [u8; 8]) -> &str {
    let is_negative = number < 0;
    let mut value = number.unsigned_abs();
    let mut index = buffer.len();

    if value == 0 {
        index -= 1;
        buffer[index] = b'0';
    }

    while value > 0 {
        index -= 1;
        buffer[index] = b'0' + (value % 10) as u8;
        value /= 10;
    }

    if is_negative {
        index -= 1;
        buffer[index] = b'-';
    }

    core::str::from_utf8(&buffer[index..]).unwrap()
}

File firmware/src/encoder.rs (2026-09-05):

use embedded_hal::digital::OutputPin;
use rp2040_hal::gpio::bank0::{Gpio10, Gpio8, Gpio9};
use rp2040_hal::gpio::{FunctionSioInput, FunctionSioOutput, Pin, PullDown, PullUp};
use rotary_encoder_hal::{DefaultPhase, Direction, Rotary};

type PinA = Pin<Gpio10, FunctionSioInput, PullUp>;
type PinB = Pin<Gpio8, FunctionSioInput, PullUp>;
type GndPin = Pin<Gpio9, FunctionSioOutput, PullDown>;

// what happened to the encoder since the last update
pub enum Rot {
    None,
    Cw,
    Ccw,
}

pub struct Encoder {
    rot: Rotary<PinA, PinB, DefaultPhase>,
    _gnd: GndPin, // gp9 is wired straight to the encoder's gnd pin
}

impl Encoder {
    pub fn new(pin_a: PinA, pin_b: PinB, mut gnd: GndPin) -> Self {
        gnd.set_low().unwrap(); // give the encoder a ground to use
        Encoder {
            rot: Rotary::new(pin_a, pin_b),
            _gnd: gnd,
        }
    }

    pub fn upd(&mut self) -> Rot {
        match self.rot.update().unwrap() {
            Direction::Clockwise => Rot::Cw,
            Direction::CounterClockwise => Rot::Ccw,
            Direction::None => Rot::None,
        }
    }
}

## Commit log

2026-08-20 oxidekeys_wirediagram.drawio.png を追加しました。
2026-08-21 oxidekeys_wirediagram.drawio.png を更新
2026-08-21 Add rp2040 firmware framework body based on the official rp2040-hal blinky example just for now
2026-08-26 Update BOM with new components and total cost
    Added new items including better keycaps, a piezo buzzer, and a soldering iron kit. Updated total cost.
    [BOM.csv]
2026-08-27 Update BOM with new items and price adjustments
    Updated prices for several components and added new items.
    [BOM.csv]
2026-08-27 Modify BOM with updated components and notes
    Updated quantities and prices for components and added a note regarding the removal of a capacitor.
    [BOM.csv]
2026-08-27 Modify BOM.csv with updated parts and notes
    Updated BOM.csv to reflect changes in components and notes.
    [BOM.csv]
2026-08-27 Revise BOM with updated component notes and prices
    Updated BOM.csv to reflect changes in component specifications and pricing.
    [BOM.csv]
2026-08-29 Update BOM with supplier changes and notes
    Updated supplier information for Clear Acrylic Sheet and modified note regarding the 470uF electrolytic cap.
    [BOM.csv]
2026-09-01 Modify BOM.csv with updated parts and prices
    Updated BOM to reflect changes in parts and prices, including additions and removals.
    [BOM.csv]
2026-09-02 Fix formatting issues in BOM.csv
    [BOM.csv]
2026-09-02 Add PCB gerbers/KiCad files
    [pcbfirstdesign.kicad_pcb, pcbfirstdesign.kicad_sch]
2026-09-02 Add enclosure CAD file
2026-09-02 add pcb images
2026-09-02 add schematic images
2026-09-03 Refine component descriptions in BOM.csv
    Updated descriptions for various components to clarify specifications and verify compatibility.
    [BOM.csv]
2026-09-03 Fix formatting in BOM.csv for soldering iron entry
2026-09-03 Update BOM.csv with new parts and descriptions
    [BOM.csv]
2026-09-03 Update BOM.csv with new rotary encoder details
    [BOM.csv]
2026-09-03 fix firmware build errors
    [buzzer.rs, display.rs, encoder.rs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]
2026-09-03 Add Group and Shipping columns to BOM.csv
    Updated BOM.csv to include additional columns for Group and Shipping details, and modified existing entries for clarity.
    [BOM.csv]
2026-09-03 Update BOM.csv by removing shipping confirmation note
    Removed confirmation note for LCSC shipping in BOM.
    [BOM.csv]
2026-09-04 fix enclosure svg
2026-09-07 Update BOM.csv with additional parts and shipping
    [BOM.csv]
2026-09-07 Update BOM.csv with revised item descriptions
    [BOM.csv]
2026-09-07 Update BOM.csv with new supplier and shipping details
    [BOM.csv]
2026-09-07 Update BOM.csv with new item details and prices
    [BOM.csv]
2026-09-07 Update BOM.csv with new products and pricing
    Updated BOM.csv to reflect changes in product names, prices, and sources. Removed obsolete items and added new entries.
    [BOM.csv]
2026-09-07 Update BOM with new suppliers and prices
    [BOM.csv]
2026-09-26 Add Oxide Keys CAD and production review package
    [OxideKeys-review-assembly.step, base-plate.step, display-flap-open.step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]
2026-09-26 Build production UF2 and expand detailed CAD in CI
2026-09-26 Fix CAD spacer contact and production build target
    [OxideKeys-review-assembly.step, base-plate.step]
2026-09-26 Add built RP2040 UF2 and detailed STEP assembly
    [OxideKeys-review-assembly-detailed.step]
2026-09-26 Document verified firmware and CAD clearance limits
2026-09-26 Clear modeled enclosure clashes and document finish checks
2026-09-26 Build verified firmware and enclosure review models
    [OxideKeys-review-assembly-detailed.step, OxideKeys-review-assembly.step, base-plate.step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]
2026-09-26 Show switch and LED placements in CAD assembly
    [OxideKeys-review-assembly-detailed.step, OxideKeys-review-assembly.step, leds.step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]
2026-09-26 Show BOM hardware in complete CAD review assembly
    [OxideKeys-review-assembly-detailed.step, OxideKeys-review-assembly.step, base-plate.step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]
2026-09-26 Fix CAD preview rendering and simplify README
2026-09-26 Improve assembly CAD views and note display wiring issue
    [OxideKeys-review-assembly-detailed.step, OxideKeys-review-assembly.step, keycaps.step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]
2026-09-26 Note SW5 wiring issue
2026-10-05 Source blank keycaps from AliExpress
    [BOM.csv]
2026-10-05 Update BOM table for AliExpress keycaps
2026-10-05 Add cheap Desertcart M2 screw option
    [BOM.csv]
2026-10-05 Document Desertcart M2 screw option
2026-10-05 Use cheaper N3UD blank keycaps
    [BOM.csv]
2026-10-05 Update keycap price and BOM total
2026-10-05 Count PCB fabrication toward project budget
    [BOM.csv]
2026-10-05 Update BOM total with PCB cost
2026-10-07 Revise README with project updates and corrections
    Updated README.md to include additional project details and corrections regarding PCB issues and hardware components.
2026-10-08 Reorganize repo into cad/pcb/firmware, remove zips and old workflow
    [OxideKeys-review-assembly-detailed.step, OxideKeys-review-assembly.step, base-plate.step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]
2026-10-08 Reorganize repo into cad/pcb/firmware, remove zips, update README
